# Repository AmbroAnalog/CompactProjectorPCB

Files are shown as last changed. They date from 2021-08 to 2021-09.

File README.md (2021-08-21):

# DIY CompactProjector Project

A compact 64x32 LCD monocrom projector build on the Project [diy-projector-clock](https://github.com/shufps/diy-projector-clock).
Perfectly suited for installation in narrow spaces with board dimensions of 38x86mm.

The LCD as well as the LED are controlled by an Arduino Pro Mini. The data for the Arduino can be sent via serial connection.

## List of components

  * 64x32 I2C LCD Screen ([allegro.pl](https://allegro.pl/oferta/art-lcd-vatn-64x32-3v-st7567a-i2c-15x12x2mm-whiten-6754828746))
  * 25mm C Mount Lens ([ebay.com](https://www.ebay.com/itm/255067829058?hash=item3b633a3342:g:b3sAAOSwA~9hBQYL))
  * Arduino Pro Mini 3,3V ([aliexpress.com](https://de.aliexpress.com/item/32821902128.html?spm=a2g0s.9042311.0.0.4a384c4dcQsU7K))
  * LED Lens ([aliexpress.com](https://de.aliexpress.com/item/1322969782.html?spm=a2g0s.9042311.0.0.4a384c4dcQsU7K))
  * BOM for PCB available in subfolder

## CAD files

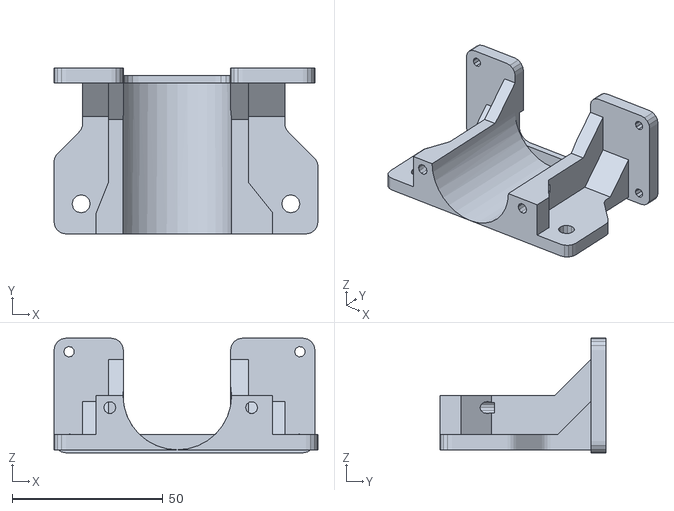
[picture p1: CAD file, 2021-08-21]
ProjectorLensMount.stl
87.5 x 55.0 x 38.0

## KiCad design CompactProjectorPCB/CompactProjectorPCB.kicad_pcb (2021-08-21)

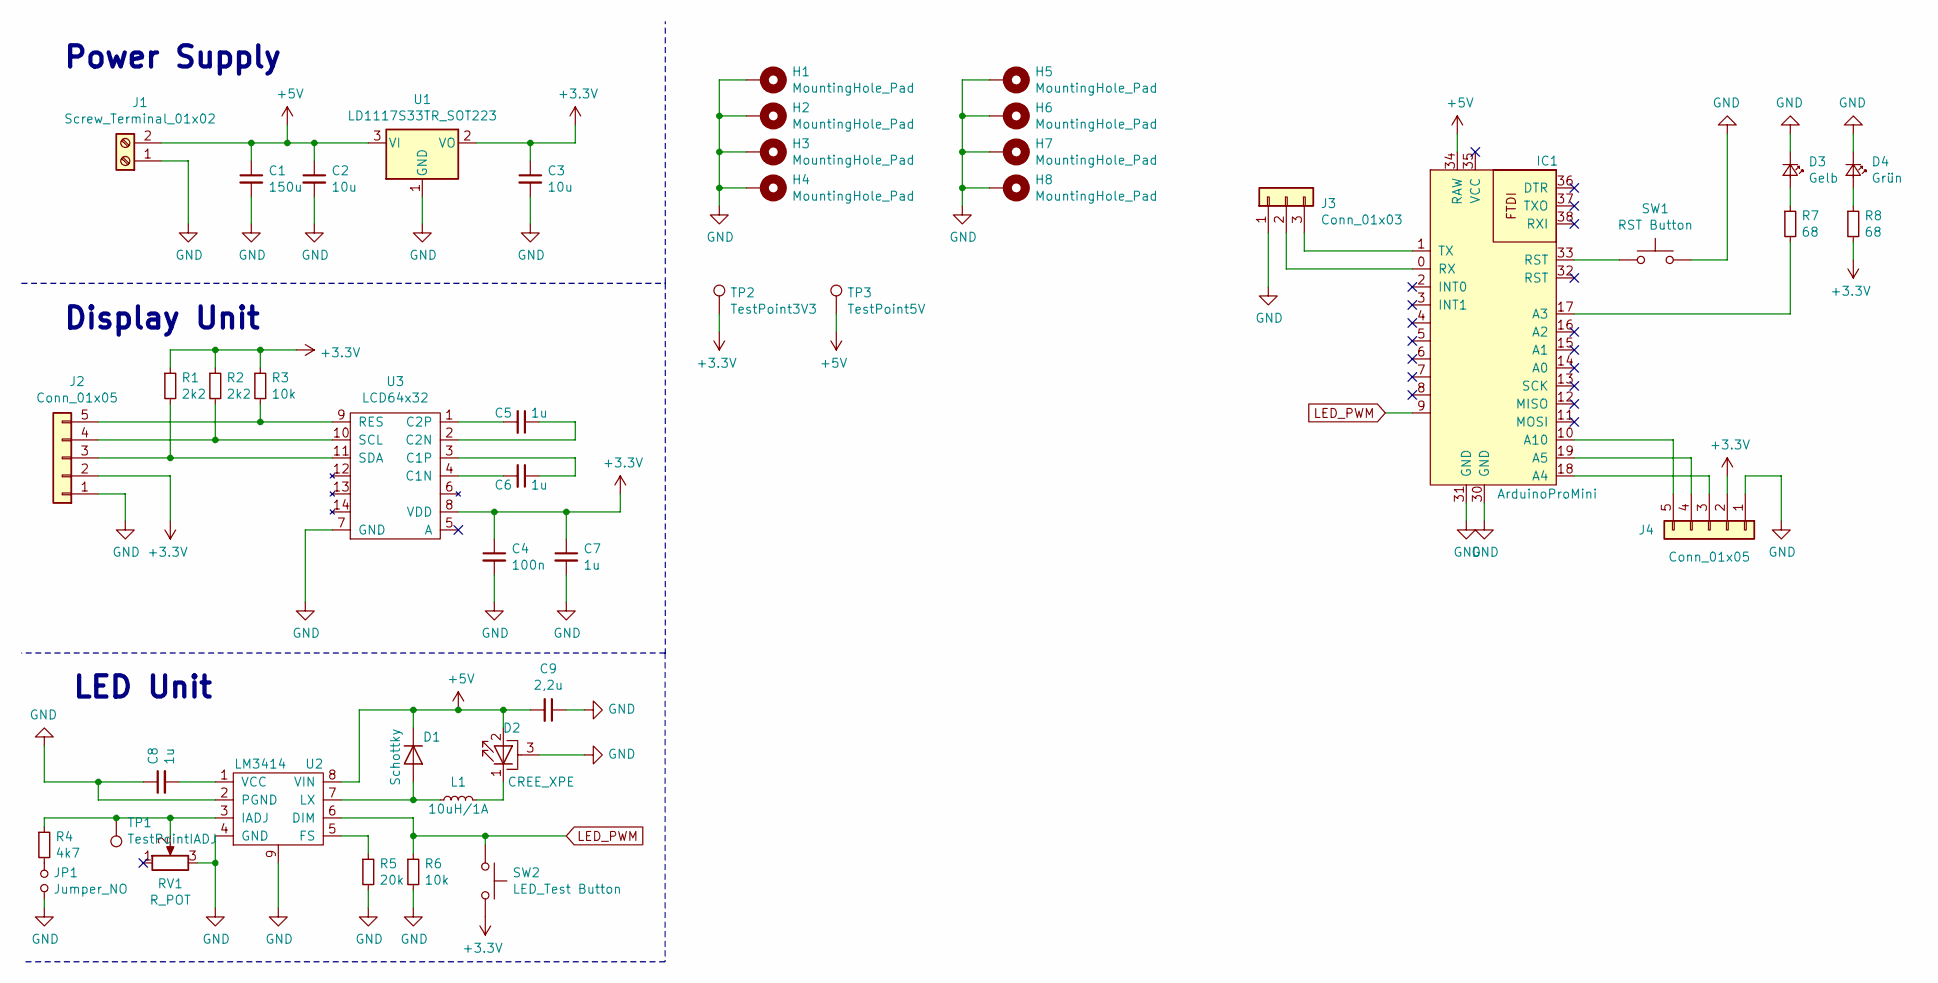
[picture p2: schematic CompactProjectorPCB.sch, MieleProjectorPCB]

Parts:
C1: 150u; CP_Elec_8x6.7
C2, C3: 10u; C_1206_3216Metric_Pad1.42x1.75mm_HandSolder
C4: 100n; C_1206_3216Metric_Pad1.42x1.75mm_HandSolder
C5, C6, C7, C8: 1u; C_1206_3216Metric_Pad1.42x1.75mm_HandSolder
C9: 2,2u; C_1206_3216Metric_Pad1.42x1.75mm_HandSolder
D1: Schottky; DO-220AA; Mouser # 625-SS2PH10-M3
D2: CREE_XPE; LED_Cree-XP; Mouser # 941-XPEWHTL100AE5
D3: Gelb; LED_1206_3216Metric_Pad1.42x1.75mm_HandSolder
D4: Grün; LED_1206_3216Metric_Pad1.42x1.75mm_HandSolder
H1, H2, H3, H4, H5, H6, H7, H8: MountingHole_Pad; MountingHole_3.2mm_M3_Pad_Via
IC1: ArduinoProMini; Arduino_ProMini
J1: Screw_Terminal_01x02; Wago_2060-1872_1x02
J2, J4: Conn_01x05; Molex_PicoBlade_53261-0571_1x05-1MP_P1.25mm_Horizontal
J3: Conn_01x03; Molex_PicoBlade_53261-0371_1x03-1MP_P1.25mm_Horizontal
JP1: Jumper_NO; SolderJumper-2_P1.3mm_Open_TrianglePad1.0x1.5mm
L1: 10uH/1A; Wurth_WE-TPC_744043100; Mouser # 710-744043100
R1, R2: 2k2; R_1206_3216Metric_Pad1.42x1.75mm_HandSolder
R3, R6: 10k; R_1206_3216Metric_Pad1.42x1.75mm_HandSolder
R4: 4k7; R_1206_3216Metric_Pad1.42x1.75mm_HandSolder
R5: 20k; R_1206_3216Metric_Pad1.42x1.75mm_HandSolder
R7, R8: 68; R_1206_3216Metric_Pad1.42x1.75mm_HandSolder
RV1: R_POT; Potentiometer_Bourns_3266X_Horizontal
SW1: RST Button; Schurter_1241.1600
SW2: LED_Test Button; Schurter_1241.1600
TP1: TestPointIADJ; TestPoint_THTPad_3.0x3.0mm_Drill1.5mm
TP2: TestPoint3V3; TestPoint_THTPad_3.0x3.0mm_Drill1.5mm
TP3: TestPoint5V; TestPoint_THTPad_3.0x3.0mm_Drill1.5mm
U1: LD1117S33TR_SOT223; SOT-223-3_TabPin2
U2: LM3414; SOIC-8-1EP_3.9x4.9mm_P1.27mm_EP2.29x3mm_ThermalVias; Mouser # 926-LM3414HVMRX/NOPB
U3: LCD64x32

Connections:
+3V3: C3.1, C4.1, C7.1, J2.2, J4.2, R1.1, R2.1, R3.1, R8.2, SW2.2, TP2.1, U1.2 (VO), U3.8 (VDD)
+5V: C1.1, C2.1, C9.2, D1.1 (K), D2.2 (A), IC1.34 (RAW), J1.2, TP3.1, U1.3 (VI), U2.8 (VIN)
GND: C1.2, C2.2, C3.2, C4.2, C7.2, C8.1, C9.1, D2.3 (PAD), D3.1 (K), D4.1 (K), H1.1, H2.1, H3.1, H4.1, H5.1, H6.1, H7.1, H8.1, IC1.30 (GND), IC1.31 (GND), J1.1, J2.1, J3.1, J4.1, JP1.2, R5.2, R6.2, RV1.3, SW1.2, U1.1 (GND), U2.2 (PGND), U2.4 (GND), U2.9, U3.7 (GND)
LED_PWM: IC1.9, R6.1, SW2.1, U2.6 (DIM)
unnamed: C5.1, U3.2 (C2N)
unnamed: C5.2, U3.1 (C2P)
unnamed: C6.1, U3.3 (C1P)
unnamed: C6.2, U3.4 (C1N)
unnamed: C8.2, U2.1 (VCC)
unnamed: D1.2 (A), L1.1, U2.7 (LX)
unnamed: D2.1 (K), L1.2
unnamed: D3.2 (A), R7.1
unnamed: D4.2 (A), R8.1
unnamed: IC1.0 (RX), J3.2
unnamed: IC1.1 (TX), J3.3
unnamed: IC1.10 (A10), J4.5
unnamed: IC1.17 (A3), R7.2
unnamed: IC1.18 (A4), J4.3
unnamed: IC1.19 (A5), J4.4
unnamed: IC1.33 (RST), SW1.1
unnamed: J2.3, R1.2, U3.11 (SDA)
unnamed: J2.4, R2.2, U3.10 (SCL)
unnamed: J2.5, R3.2, U3.9 (RES)
unnamed: JP1.1, R4.2
unnamed: R4.1, RV1.2, TP1.1, U2.3 (IADJ)
unnamed: R5.1, U2.5 (FS)

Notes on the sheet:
Power Supply
Display Unit
LED Unit

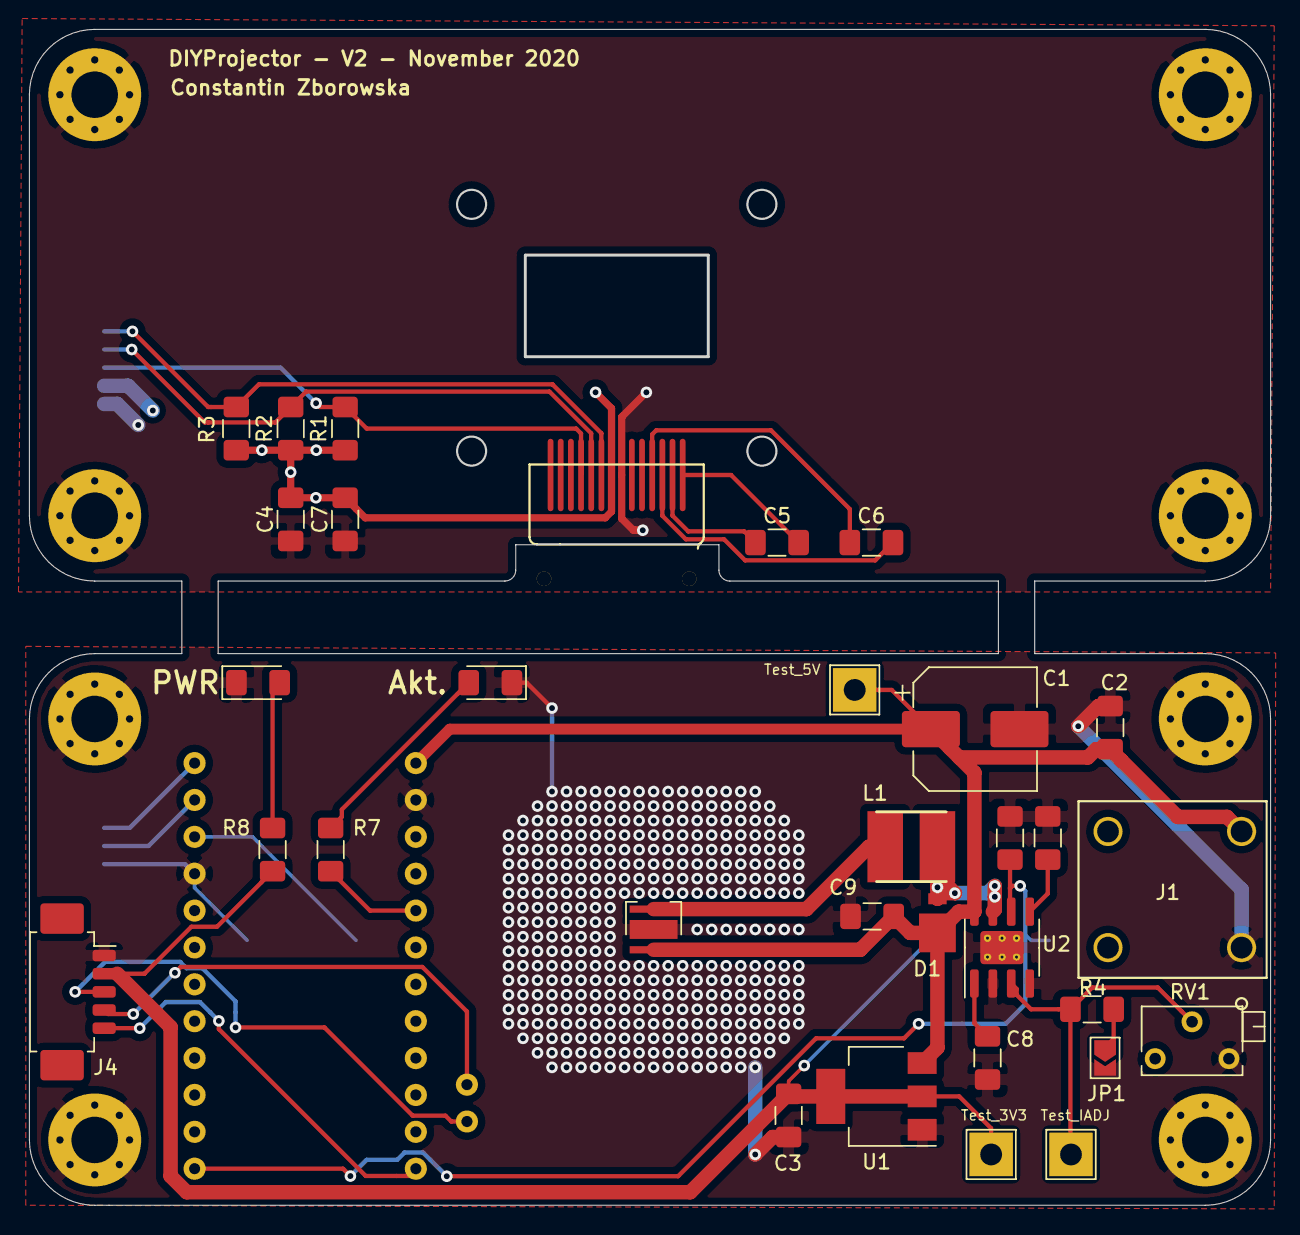
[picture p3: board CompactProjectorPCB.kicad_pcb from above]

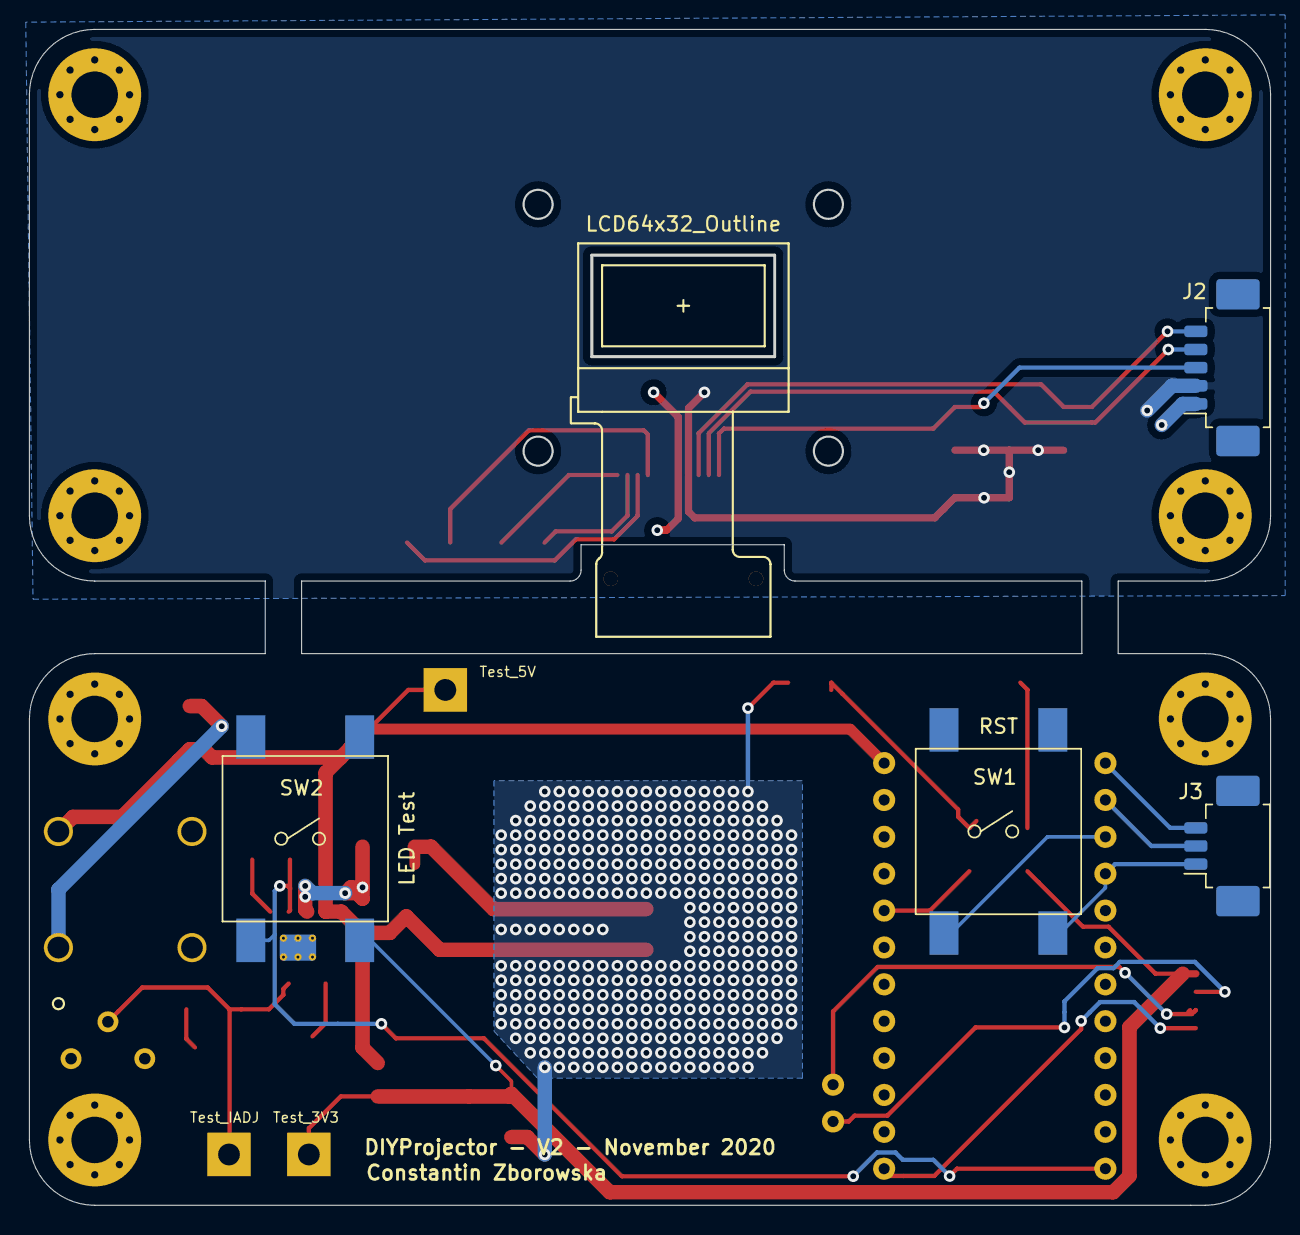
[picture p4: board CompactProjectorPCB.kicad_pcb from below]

Board: 2 copper layers, 85.5 x 81.0 mm, 45 parts (4 on the bottom side), 26 nets.

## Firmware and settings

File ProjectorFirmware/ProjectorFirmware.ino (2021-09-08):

#include <Arduino.h>
#include <SPI.h>
#include <U8g2lib.h>

#define LCDWidth           u8g2.getDisplayWidth()
#define ALIGN_CENTER(t)    ((LCDWidth - (u8g2.getUTF8Width(t))) / 2)
#define ALIGN_RIGHT(t)     (LCDWidth -  u8g2.getUTF8Width(t))
#define ALIGN_LEFT         0

#define PIN_LCD_RESET 10
#define PIN_STATUS_LED 17
#define PIN_PWM_LED 9

//only for debug
#define PIN_DEBUG_A 2
#define PIN_DEBUG_B 3
#define PIN_DEBUG_C 4
#define PIN_DEBUG_D 5
#define PIN_DEBUG_E 6
#define PIN_DEBUG_F 7
#define PIN_DEBUG_G 8

/*
  Projector Firmware von Constantin Zborowska
  Start 30.12.2020
  Version 07.09.2021
  
  
  Programmiert für die Verwendung mit MieleSmartG470

  Serial Data Befehl:

  BEFEHL: ETE0000PR000T00M0U0E0A0H0X
  EINHEIT:    s    %  °C

  Wenn PR > 100 wird die Projector LED Deaktiviert
  
*/

U8G2_ST7567_HEM6432_F_HW_I2C u8g2(U8G2_R0, /* reset=*/ PIN_LCD_RESET);

char serialReceiveArray[32];
char restTemp[] = "0000";
bool serialReceiveComplete = false;
bool serialReceiveTotal = false;
int serialReceiveByteCount = 0;

//Display Informations
int ete_timer = 0; //in seconds
int temperatur = 0;
int progress = 0;
bool statusIntake = true;
bool statusOuttake = true;
bool statusCirculator = true;
bool statusHeater = true;

bool beamerLEDOn = true;
bool forceOff = false;
/* Program State
 * 1 = pre run time
 * 2 = in run
 * 3 = after one run in standby
 * 4 = complete off
 */
int programState = 1;

int glow_counter = 0;
int ani_counter = 0;
bool ani_statusHeater = false;
bool ani_statusIntake = false;
bool ani_statusOuttake = false;
bool ani_statusCirculator = false;
bool ani_cursor = false;
char *timeToChars = (char*)malloc(2);

long timer_last_exec = 0;
long timer_start = 0;
long timer_end = 0;

void setup(void) {
  Serial.begin(9600);
  u8g2.setBusClock(70000);
  u8g2.begin();

  pinMode(PIN_STATUS_LED, OUTPUT);
  pinMode(PIN_PWM_LED, OUTPUT);
  analogWrite(PIN_PWM_LED, 0);

  u8g2.setDisplayRotation(U8G2_R2);

  u8g2.clearBuffer();
  u8g2.setFont(u8g2_font_t0_22b_mr);
  u8g2.drawUTF8(ALIGN_CENTER("MIELE"), 28, "MIELE");
  u8g2.sendBuffer();
  
  delay(1000);
  timer_start = millis();
  //Serial.println("Start Programm");
}

void loop(void) {
  u8g2.clearBuffer();
  u8g2.setFont(u8g2_font_crox4hb_tf);
  u8g2.setContrast(255);
  
  //Serial Received Loop
  while (Serial.available() > 0) {
    serialReceiveArray[serialReceiveByteCount] = Serial.read();
    if (serialReceiveArray[serialReceiveByteCount] == 'X') {
      if (serialReceiveTotal) {
        serialReceiveComplete = true; 
      } else {
        serialReceiveComplete = false;
        serialReceiveByteCount = 0;
      }
      serialReceiveTotal = true;
      break;
    }
    if (serialReceiveByteCount > 30) {
      serialReceiveByteCount = 0;
      serialReceiveTotal = false;
      break;
    } else {
      serialReceiveByteCount+=1;
    }
  }
  //Update Device Status on Serial Receive
  if (serialReceiveComplete) {
    //read ETE
    restTemp[0] = serialReceiveArray[3];
    restTemp[1] = serialReceiveArray[4];
    restTemp[2] = serialReceiveArray[5];
    restTemp[3] = serialReceiveArray[6];
    ete_timer = atoi(restTemp);
    restTemp[0] = '0';
    restTemp[1] = serialReceiveArray[9];
    restTemp[2] = serialReceiveArray[10];
    restTemp[3] = serialReceiveArray[11];
    progress = atoi(restTemp);
    if (progress > 100 || forceOff) {
      beamerLEDOn = false;
      programState = 3;
      timer_start = millis();
    } else {
      beamerLEDOn = true;
    }
    if (programState == 1) {
        analogWrite(PIN_PWM_LED, 255);
        programState = 2;
        ani_counter = 0;
    }
    restTemp[0] = '0';
    restTemp[1] = '0';
    restTemp[2] = serialReceiveArray[13];
    restTemp[3] = serialReceiveArray[14];
    temperatur = atoi(restTemp);
    statusCirculator = (serialReceiveArray[18] == '1') ? true : false;
    statusIntake = (serialReceiveArray[20] == '1') ? true : false;
    statusOuttake = (serialReceiveArray[22] == '1') ? true : false;
    statusHeater = (serialReceiveArray[24] == '1') ? true : false;
    serialReceiveComplete = false;
    serialReceiveByteCount = 0;  
    digitalWrite(PIN_STATUS_LED, true);
  }

  if (programState == 2) {
    //display function for in progress
    display_process_inrun();
  } else if (programState == 3) {
    u8g2.setFont(u8g2_font_t0_22b_mr);
    u8g2.drawUTF8(ALIGN_CENTER("ENDE"), 28, "ENDE");
  } else if (programState == 4) {
    analogWrite(PIN_PWM_LED, 0);  
  }

  //send data to the display
  u8g2.sendBuffer();

  if (programState == 1) {
    if (ani_counter % 40 == 0) {
      digitalWrite(PIN_STATUS_LED, true);
    }
    delay(100);
    ani_counter++;
    digitalWrite(PIN_STATUS_LED, false);
  } else if (programState == 2) {
    delay(80);
    if (ani_counter % 30 == 0) {
      digitalWrite(PIN_STATUS_LED, true);
    }
    delay(20);
    ani_counter++;
    digitalWrite(PIN_STATUS_LED, false);
  } else if (programState == 3) {
    digitalWrite(PIN_STATUS_LED, true);
    for (glow_counter = 0; glow_counter <= 255; glow_counter++) {
        analogWrite(PIN_PWM_LED, glow_counter);
        delay(8);
    }
    digitalWrite(PIN_STATUS_LED, false);
    delay(800);
    for (glow_counter = 255; glow_counter >= 0; glow_counter--) {
        analogWrite(PIN_PWM_LED, glow_counter);
        delay(8);
    }
    delay(14000);
    //Calculate for max on time
    if (millis() > timer_start + 14400000) {
        programState = 4;
    }
  } else if (programState == 4) {
    delay(10000);
  }
}

void display_process_inrun() {
  //DISPLAY DETALS
  u8g2.setFont(u8g2_font_u8glib_4_tf);
  if (ani_statusHeater && statusHeater) { u8g2.drawGlyph(2, 9, 0x007e); }
  u8g2.setCursor(8, 7);
  u8g2.print(temperatur);
  u8g2.drawUTF8(16, 7, "°C");
  //intake indicator
  if (ani_statusIntake && statusIntake) { u8g2.drawGlyph(46, 7, 0x00bb); }
  u8g2.drawGlyph(50, 7, 0x007f); //maschine symbol
  if (ani_statusCirculator && statusCirculator) { u8g2.drawBox(51, 5, 1, 1); }
  if (!ani_statusCirculator && statusCirculator){ u8g2.drawBox(52, 5, 1, 1); }
  if (ani_statusOuttake && statusOuttake) {u8g2.drawGlyph(55, 7, 0x00bb); }

  //DISPLAY ETE
  u8g2.setFont(u8g2_font_crox4hb_tf);
  u8g2.setCursor(ALIGN_CENTER("00:00"), 24);
  int laufende_minute = 0;
  int laufende_sekunde = 0;
  laufende_minute = ete_timer/60;
  laufende_sekunde = ete_timer-(laufende_minute*60);
  sprintf(timeToChars, "%02d", laufende_minute);
  u8g2.print(timeToChars);
  u8g2.print(":");
  sprintf(timeToChars, "%02d", laufende_sekunde);
  u8g2.print(timeToChars);
  
  //DISPLAY PROGRESSBAR ----------------------
  //float percent = progress / 100;
  int PixelProgress = (int) (62 * ((float) progress / 100));
  u8g2.drawRFrame(0, 27, 64, 5, 1);
  u8g2.drawBox(1, 28, 1+PixelProgress, 3);
  if (ani_cursor && progress < 100) {
    u8g2.drawBox(2+PixelProgress, 28, 1, 3); //cursor
  }
  
  if (millis() > timer_last_exec + 1000) {
    timer_last_exec = millis();
    if (ete_timer > 0) { ete_timer--; }
    ani_counter=0;
  }

  //ANIMATION STEPPS
  if (ani_counter % 20 == 0) { //langsam
    ani_statusHeater = !ani_statusHeater;
    ani_cursor = !ani_cursor;
  }
  if (ani_counter % 10 == 0) {
    ani_statusCirculator = !ani_statusCirculator;
  }
  if (ani_counter % 4 == 0) { //schnell
    ani_statusIntake = !ani_statusIntake;
    ani_statusOuttake = !ani_statusOuttake;
  }
}

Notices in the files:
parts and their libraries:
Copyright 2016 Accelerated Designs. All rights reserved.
